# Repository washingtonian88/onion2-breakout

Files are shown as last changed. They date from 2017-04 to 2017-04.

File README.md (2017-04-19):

# onion2-breakout
Breakout board for the onion omega 2 with 5V power provided by a micro-USB connector and an interface for connecting a USB device to the Omega2.

---
This is my first attempt at designing a PCB. I decided to use KiCAD due to mild-familiarity with it and its open nature. The components were chosen to be cheap and easy to obtain (via ebay). Total cost per board is < $10 fully assembled, can be made cheaper by not populating some of the parts (USB connectors and pin headers).

---
### ToDo (before ordering):
* ~~Validate foot print for USB interfaces~~
* ~~Make sure the 2.54mm pins are spaced so they will fit on a 'normal' pcb~~
* ~~Consult some guru's on layout / design~~

---
### Rev 1 ORDERED!
Bought all of the components on eBay minus the 2.54mm 1x16 pin headers for ~$40 USD to build 10 boards. Here's to hoping for a strong tail wind for the boat. For the first round (Rev. 1) I ordered 3 boards from OSHPark.com (https://oshpark.com/shared_projects/boUh3Ezt) for $16 shipped.

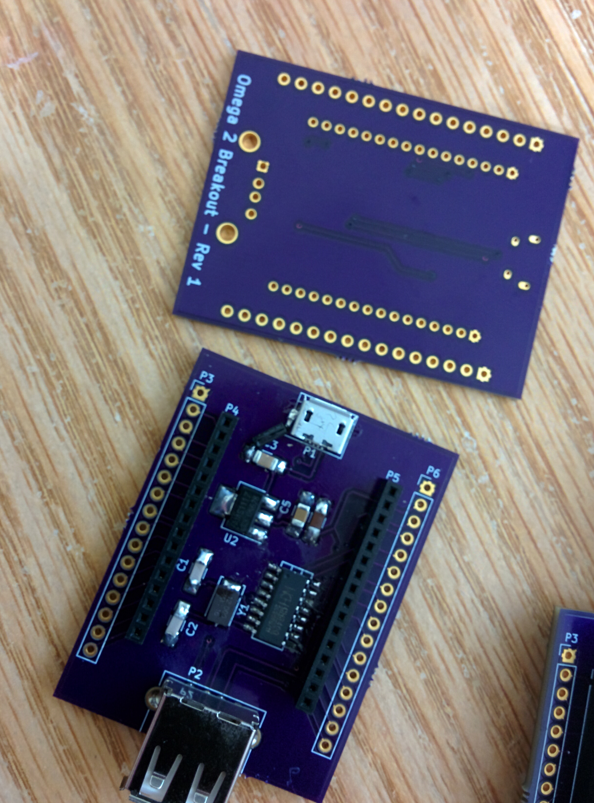
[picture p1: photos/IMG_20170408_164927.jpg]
Bare board from OSH Park

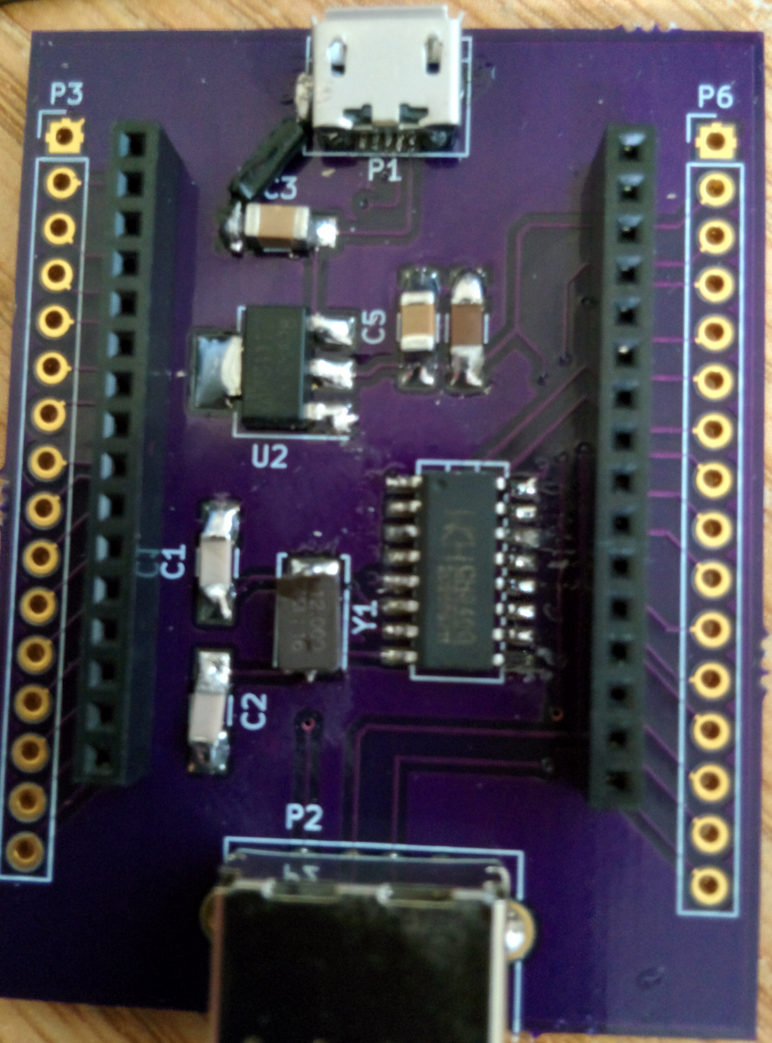
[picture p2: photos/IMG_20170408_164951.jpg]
A sky-wire was needed to connect the microUSB shield to GND due to the schematic being wrong

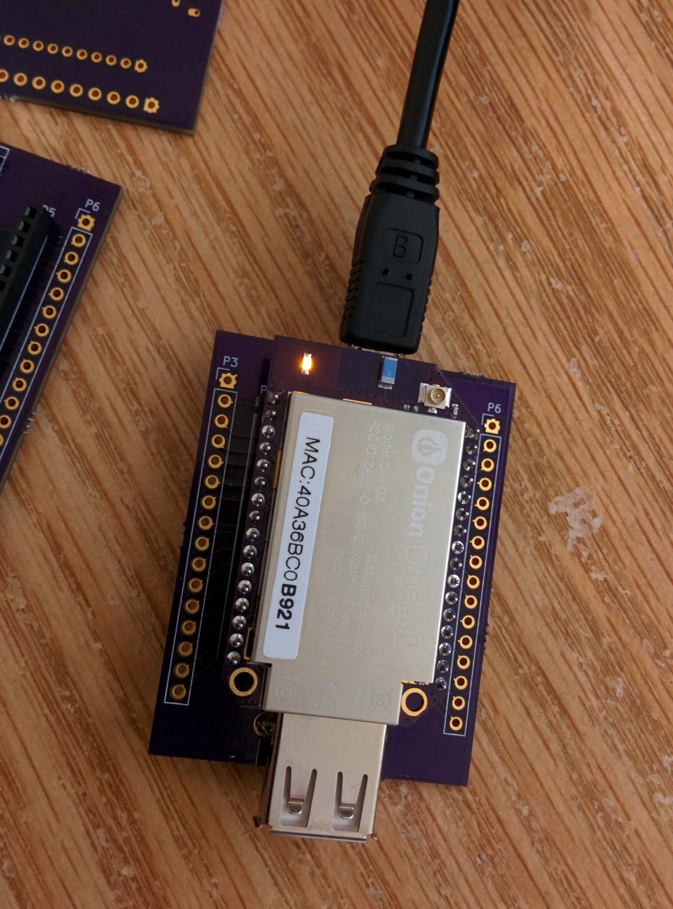
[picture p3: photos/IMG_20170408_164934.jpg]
It's working!

---
### Rev 2
Found an issue with the USB connector schematic (pins 4 and 5 were switched). I have corrected this on the schematic and board layout. I also found the clearance to be too tight for the USB-A connector and the onion board. I moved the connector down a bit to allow for more clearance. I confirmed the seral communication via the CH340G chip and confirmed the USB host abilities via the USB A connector. Rev. 2 has been uploaded to OSHPark.com (https://oshpark.com/shared_projects/nRecWv9b).

### ToDo
* ~~Modify footprint of micro USB connector to allow larger mounting feet to properly mount.~~
* ~~Verify USB host functionality.~~ Works!
```
                      * ... ?
                      * Profit!
                __
             .-'  |
            /   <\|
           /     \'
           |_.- o-o
           / C  -._)\
          /',        |
         |   `-,_,__,'
         (,,)====[_]=|
           '.   ____/
            | -|-|_
            |____)_)    
```

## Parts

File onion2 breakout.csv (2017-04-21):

Id | Designator | Package | Quantity | Designation
1 | U1 | SO-16-N | 1 | CH340G
2 | C1,C2 | C_1206_HandSoldering | 2 | 22pF
3 | C3 | C_1206_HandSoldering | 1 | 100uF
4 | C4 | C_1206_HandSoldering | 1 | 10uF
5 | C5 | C_1206_HandSoldering | 1 | 0.1uF
6 | P2 | USB_A | 1 | USB_B
7 | P3,P6 | Pin_Header_Straight_1x16_Pitch2.54mm | 2 | CONN_01X16
8 | P4,P5 | Pin_Header_Straight_1x16_Pitch2.00mm | 2 | CONN_01X16
9 | Y1 | Crystal_SMD_5032-2pin_5.0x3.2mm | 1 | 12MHz
10 | U2 | SOT-223 | 1 | AP1117
11 | P1 | USB_Micro-B | 1 | USB_B
12 | PCB | PCB Board 1.57"x2.05 | 1 | PCB

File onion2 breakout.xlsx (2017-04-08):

Id | Designator | Package | Quantity | Designation | Supplier | Quantity ordered | cost | unit cost | cost per board | Shipped Date | Tracking | Est delivery | Received?
1 | U1 | SO-16-N | 1 | CH340G | eBay | 10 | 4.79 | 0.479 | 0.479 | 2017-03-11 | HK05232788AM | 3/24-4/3 | F
2 | C1,C2 | C_1206_HandSoldering | 2 | 22pF | eBay | 50 | 1.69 | 0.0338 | 0.0676 | 2017-03-11 | LK185171893CN | 3/29-5/6 | T
3 | C3 | C_1206_HandSoldering | 1 | 100uF | eBay | 50 | 6.5 | 0.13 | 0.13 | 2017-03-11 | LK185171893CN | 3/29-5/7 | T
4 | C4 | C_1206_HandSoldering | 1 | 10uF | eBay | 50 | 2.99 | 0.0598 | 0.0598 | 2017-03-11 | LK185171893CN | 3/29-5/8 | T
5 | C5 | C_1206_HandSoldering | 1 | 0.1uF | eBay | 50 | 1.69 | 0.0338 | 0.0338 | 2017-03-11 | LK185171893CN | 3/29-5/9 | T
6 | P2 | USB_A | 1 | USB_B | eBay | 10 | 5.51 | 0.551 | 0.551 |  | 9.200190177e+21 | 2017-03-18 | T
7 | P3,P6 | Pin_Header_Straight_1x16_Pitch2.54mm | 2 | CONN_01X16 |  | 1 | 0 | 0 | 0 |  |  |  | F
8 | P4,P5 | Pin_Header_Straight_1x16_Pitch2.00mm | 2 | CONN_01X16 | eBay | 20 | 5.99 | 0.2995 | 0.599 |  |  | 3/21-4/6 | T
9 | Y1 | Crystal_SMD_5032-2pin_5.0x3.2mm | 1 | 12MHz | eBay | 10 | 4.95 | 0.495 | 0.495 |  |  |  | T
10 | U2 | SOT-223 | 1 | AP1117 | eBay | 10 | 2.89 | 0.289 | 0.289 |  |  | 2017-03-18 | T
11 | P1 | USB_Micro-B | 1 | USB_B | eBay | 10 | 2.35 | 0.235 | 0.235 |  |  | 3/29-5/5 | F
12 | PCB | PCB Board 1.57"x2.05 | 1 | PCB | OshPark | 3 | 16 | 5.333333333 | 5.333333333 |  |  |  | T
 |  |  |  |  |  | Totals: | 55.35 |  | 8.272533333

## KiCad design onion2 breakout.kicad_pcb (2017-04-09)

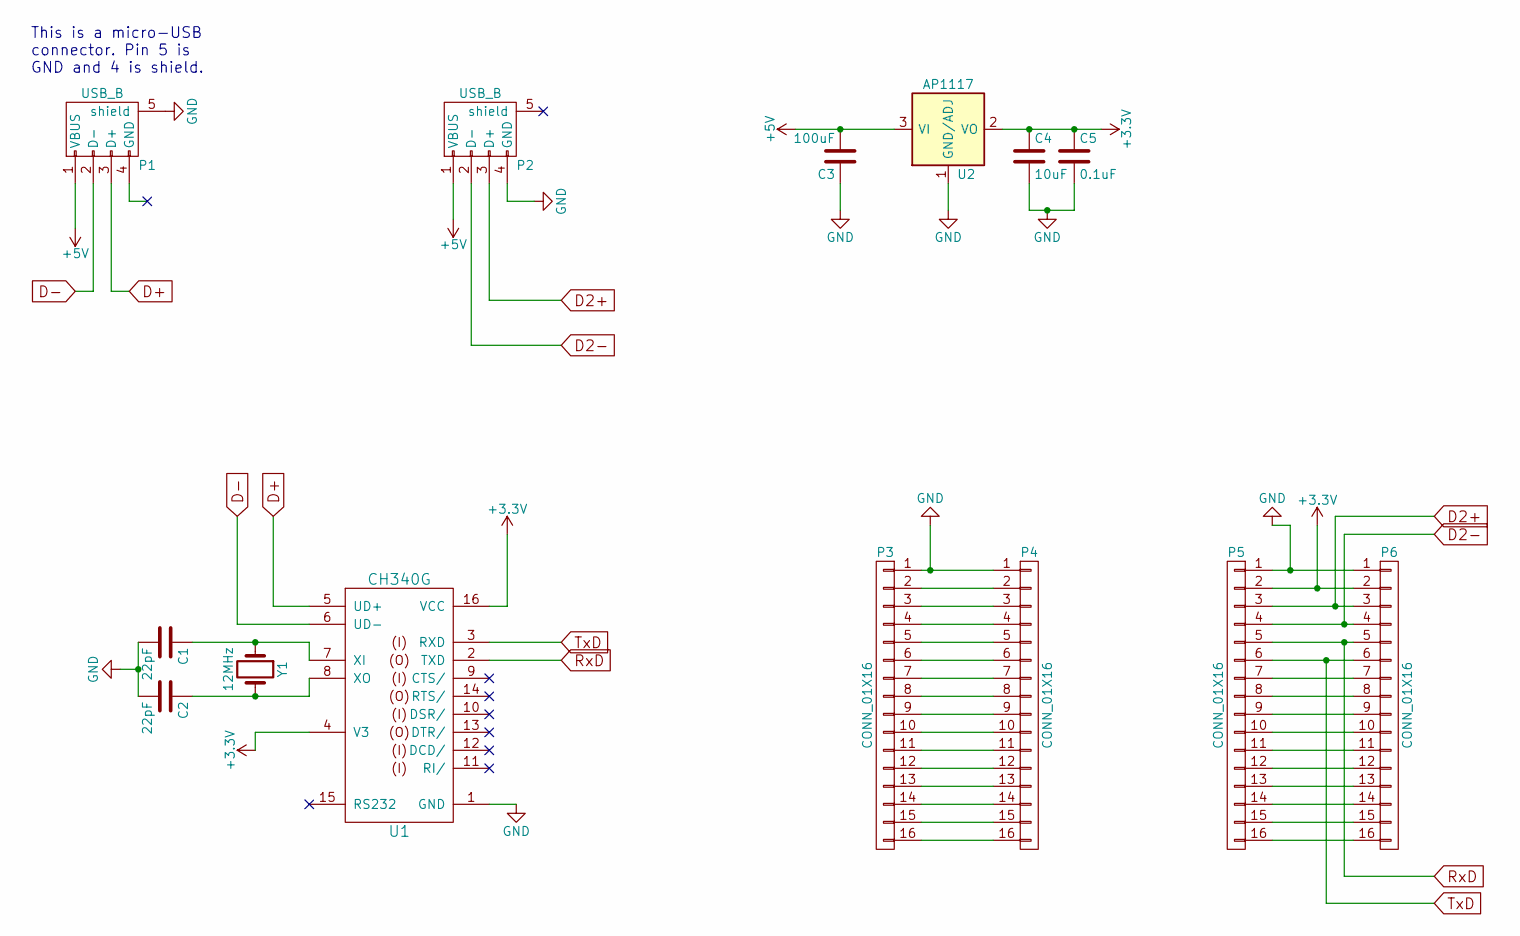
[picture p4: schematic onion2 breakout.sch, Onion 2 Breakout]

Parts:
C1, C2: 22pF; C_1206_HandSoldering
C3: 100uF; C_1206_HandSoldering
C4: 10uF; C_1206_HandSoldering
C5: 0.1uF; C_1206_HandSoldering
P1: USB_B; USB_B_MUSB_Straight
P2: USB_B; USB_A
P3, P6: CONN_01X16; Pin_Header_Straight_1x16_Pitch2.54mm
P4, P5: CONN_01X16; Pin_Header_Straight_1x16_Pitch2.00mm
U1: CH340G; SO-16-N
U2: AP1117; SOT-223
Y1: 12MHz; Crystal_SMD_HC49-SD_HandSoldering

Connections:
+3V3: C4.1, C5.1, P5.2, P6.2, U1.4 (V3), U1.16 (VCC), U2.2 (VO), U2.4 (VO)
+5V: C3.2, P1.1 (VBUS), P2.1 (VBUS), U2.3 (VI)
D2+: P2.3 (D+), P5.3, P6.3
D2-: P2.2 (D-), P5.4, P6.4
D+: P1.3 (D+), U1.5 (UD+)
D-: P1.2 (D-), U1.6 (UD-)
GND: C1.2, C2.2, C3.1, C4.2, C5.2, P1.5 (shield), P2.4 (GND), P3.1, P4.1, P5.1, P6.1, U1.1 (GND), U2.1 (GND/ADJ)
unnamed: C1.1, U1.7 (XI), Y1.1
unnamed: C2.1, U1.8 (XO), Y1.2
unnamed: P3.2, P4.2
unnamed: P3.3, P4.3
unnamed: P3.4, P4.4
unnamed: P3.5, P4.5
unnamed: P3.6, P4.6
unnamed: P3.7, P4.7
unnamed: P3.8, P4.8
unnamed: P3.9, P4.9
unnamed: P3.10, P4.10
unnamed: P3.11, P4.11
unnamed: P3.12, P4.12
unnamed: P3.13, P4.13
unnamed: P3.14, P4.14
unnamed: P3.15, P4.15
unnamed: P3.16, P4.16
unnamed: P5.7, P6.7
unnamed: P5.8, P6.8
unnamed: P5.9, P6.9
unnamed: P5.10, P6.10
unnamed: P5.11, P6.11
unnamed: P5.12, P6.12
unnamed: P5.13, P6.13
unnamed: P5.14, P6.14
unnamed: P5.15, P6.15
unnamed: P5.16, P6.16
RxD: P5.5, P6.5, U1.2 (TXD)
TxD: P5.6, P6.6, U1.3 (RXD)

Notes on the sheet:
This is a micro-USB connector. Pin 5 is GND and 4 is shield.

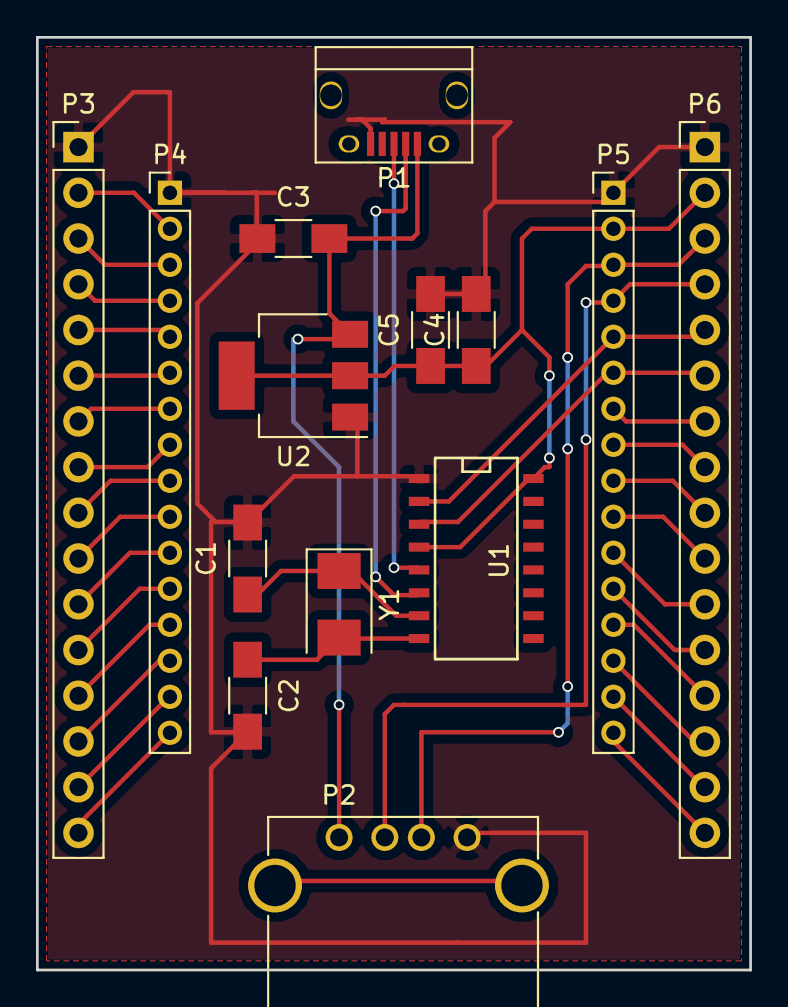
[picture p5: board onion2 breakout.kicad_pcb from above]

Board: 2 copper layers, 39.6 x 51.8 mm, 14 parts (0 on the bottom side), 36 nets.

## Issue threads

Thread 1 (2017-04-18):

Rev 2 on OSHpark?

manuti, 2017-04-18:
Are you planing to upload the Rev 2 to OSHpark?
Thanks

washingtonian88, 2017-04-19:
Just uploaded it to [OSHpark here](https://oshpark.com/shared_projects/nRecWv9b) - thanks for asking! Iv'e been having an issue getting the additional boards I ordered from indigogo and was putting off another order until they had shipped.

Hope you find the board useful :+1:

Best,
-Josef

manuti, 2017-04-19:
Thanks, I order [another board before you release](https://oshpark.com/shared_projects/GOi9e1ZF)
Now I'm waiting for the materials.
Is possible to add a BOM for your board?

washingtonian88, 2017-04-21:
No problem - I had a BOM published in the *.xlsx file. I have made a *.csv copy of this ( onion2 breakout.csv ) and have also updated the OSHpark project to have the build.

I really wanted the USB connector as well (hence the board). I used Jensa's board as inspiration, they are really quite similar, though didn't see any links to his project and thought I would share my own.

Best,
-Josef

Closed 2017-04-23.

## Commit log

2017-03-12 Fxed Rx/Tx lines from CH340G to Onion. Adjusted header spacing to accomidate onion. Changed power/data connector from USB B to USB micro. Added BOM.
    [onion2 breakout.kicad_pcb, onion2 breakout.sch, onion2 breakout.xlsx]
2017-04-08 Corrected issue with u-USB pinout. Moved USB A connector down a bit for more clearance. Rev 2.0
    [onion2 breakout.kicad_pcb, onion2 breakout.sch, onion2 breakout.xlsx]
2017-04-09 Updated footprint of microUSB connector to avoid slitted hole.
    [onion2 breakout.kicad_pcb]
2017-04-21 moved BOM from xlxs to csv
    [onion2 breakout.csv]
